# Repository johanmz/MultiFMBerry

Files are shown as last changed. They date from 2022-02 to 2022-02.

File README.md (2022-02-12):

FMBerry Logo
MultiFMBerry
=======
> Originally written by Tobias Mädel (t.maedel@alfeld.de, http://tbspace.de). Extended by Johan Muizelaar (https://github.com/johanmz) to control multiple transmitters.

> 

What is this? 
-------------
This is a fork of FMBerry from Tobias Mädel, a piece of software that allows you to transmit FM radio with your Raspberry Pi. The original software from Tobias allows you to control one transmitter, MultiFMBerry allows you to control multiple transmitters. The software is tested with 8 transmitters using a Raspberry Pi 3B but more should also be possible.

The goal was to create an alternative for analog cable FM after the switch-off, but even more just as a fun project.

How does it work? 
-------------
It uses Sony-Ericsson MMR-70 transmitters, which was originally intended for use with Sonys Walkman cellphones from early 2000s.
You can get these still for cheap from Ebay in 2022.

Why does it need additional IC's apart from the MRR70's?
-------------

Since all transmitters  use the same I²C address (0x66), one or more multiplexers (TCA9548A) are used to switch the transmitters before sending commands and RDS updates to the transmitters. Each TCA9548A has 8 I²C ports so it can handle 8 transmitters. One or more IO expanders (MCP23017) are used to read the RDS interrupt signals, this is the signal that the transmitter needs the next RDS block. Each MCP23017 can handle up to 16 transmitters. 

What do I need to build this? 
-------------
* MMR-70 transmitter, two or more. If you want to control only one transmitter, it makes more sense to use the software and hardware setup from Tobias since it doesn't need the additional IC's.
* Raspberry Pi (tested with 3B and 4B but see the limitations of the Pi4 in [AUDIO.md](audio/AUDIO.md) before you start!)
* TCA9548A, MCP23017 and AMS1117 breakout board(s) from AliExpress or Ebay
* Soldering equipment (soldering iron and some solder). Soldering skills.
* Thin wire to connect the transmitter boards to the TCA9548A and MCP23017 IC's, Dupont line cable (male to female) for the connection to the PI's GPIO connector.
* PCB prototype board (8 x 12 cm is fine, you can also mount the transmitters upright on the board) 
* USB sound card for each transmitter, the cheap "3D Sound" USB sound sticks from AliExpress work fine.
* One or more USB hubs if you have more than 4 transmitters. You need a hub with Multiple Transaction Translators (MTT). The BIG7 from UUgear and the Waveshare USB3.2 HAT (5 port) work fine and have the same form factor as the Pi as a bonus. See also [AUDIO.md](audio/AUDIO.md).

The hardware is explained here:
[HARDWARE.md](hardware/HARDWARE.md). This is my prototype with 8 MMR70 transmitters:

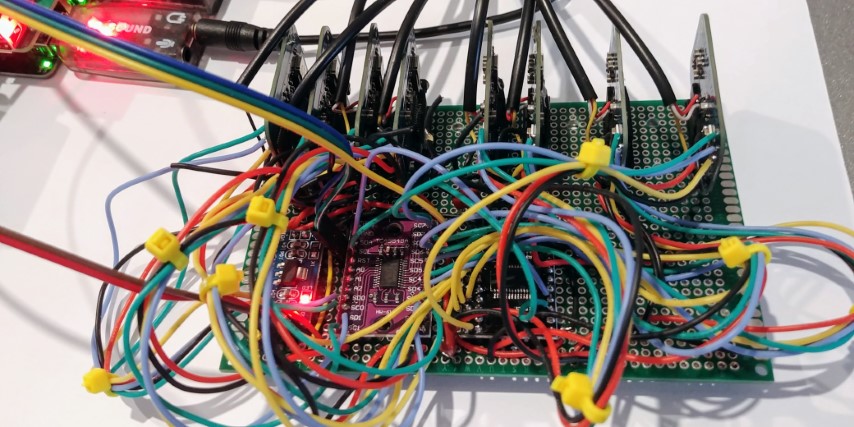
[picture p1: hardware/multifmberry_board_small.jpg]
MultiFMBerry board


How many transmitters and audio streams can one Pi control?
------------
It depends:

* The Raspberry Pi 4 has a limit of 4 USB sound cards due to limitations of the USB chipset. See [AUDIO.md](audio/AUDIO.md) for the issue and possible workarounds. On the Raspberry Pi 3B, you can use many more USB sound cards with a suitable USB hub, see next bullet.
* If you use a hub that does not support Multiple Transaction Translators (MTT), streaming to approx. more than 3 audio streams will result in severe distortion of the sound. See [AUDIO.md](audio/AUDIO.md). Use a hub with MTT.
* The Raspberry Pi OS Linux kernel has a limit of 8 sound cards. You can increase this limit by compiling your own kernel. See [AUDIO.md](audio/AUDIO.md)
* For RDS, the Pi (``fmberryd``) needs to send each 21,5ms data to each transmitter over the I²C bus. Not only the data needs to be sent but also the I²C commands to switch the multiplexer and read the IO expander. With many transmitters this will fully occupy the I²C bus, resulting in RDS display issues on the receiver. For more capacity, you can increase the speed of the I²C bus from 100Khz to 400Khz (see steps below) or disable RDS for some transmitters in the .conf file.
* Each audiostream uses about 5%-10% CPU. The Pi 3B has 4 cores which should be enough for many streams. FMBerry itself does not use much CPU either.
* The software itself has no practical limit for the number of transmitters. You need one TCA9548A per 8 transmitters and one MCP23017 per 16 transmitters. If you want to use more the 4 TCA9548A or MCP23017 IC's, increase the max in defs.h before compiling the software.

This software has been tested successfully with 8 transmitters on a Raspberry Pi 3B with 8 USB sound cards using a BIG7 UUgear USB hub, I plan to test with more transmitters. I've also done some limited but successful tests on a Pi 4B but switched to a Pi 3B when I found out about the USB sound card limit on the 4B.

Installation
-------------

### Step 1: Enabling I²C

Open raspi-blacklist.conf:

```
sudo nano /etc/modprobe.d/raspi-blacklist.conf
```

Comment out the Line "``blacklist i2c-bcm2708``" with a #.
Save with Ctrl+O and close nano with Ctrl+X

To make sure I²C Support is loaded at boottime open /etc/modules.

```
sudo nano /etc/modules
```

Add the following lines:

``i2c-dev``

Then again, Save with Ctrl+O and then close nano with Ctrl+X.

Please reboot your Raspberry after this step. 

### Step 2: Installing I²C tools and dependencies for the build

First update your local package repository with
```
sudo apt-get update
```

then install all needed software with the following command:
```
sudo apt-get install i2c-tools build-essential git libconfuse-dev
```

### Step 3: Speeding up the I²C bus

For RDS, every transmitter needs to receive data each 21,5ms over the I²C bus. Also, the I²C messages for the multiplexer and IO expander need to be send and received.  With more than 10 transmitters or so, the I²C bus speed should be increased to 400 KHz. 
```
sudo nano /boot/config.txt
```
Find the line ``dtparam=i2c`` and change it to ``dtparam=i2c_arm=on,i2c_arm_baudrate=400000``. Save and reboot.

### Step 4: Building the software
To build the software execute the following commands (in your homefolder):

```
git clone https://github.com/johanmz/MultiFMBerry.git
cd MultiFMBerry
make
```

Compiling the software will take a couple of seconds.

### Step 5: Specify your hardware in the config file
FMBerry needs to know about the MCP23017 IO expander, TCA9548A multiplexer, how many transmitters you have and to which TCA9548A and MCP23017 port each transmitter is connected. Specify this in the .conf file. 

In this file you can also specify the frequency, RDS information, etc for each transmitter.

If you want to modify the file after the make/compile, edit the fmberry.conf file in /etc.

### Step 6: Installing the software
FMBerry is essentially a daemon called fmberryd.
To install it into your system path type 
```
sudo make install
```

You can start it by typing 
```
sudo /etc/init.d/fmberry start
```

To control the daemon you have to use ctlfmberry.

It currently allows the following commands:
* ``ctlfmberry <tr> set freq 99000`` - Frequency in kHz (76000 - 108000)
* ``ctlfmberry <tr> poweron``
* ``ctlfmberry <tr> poweroff``
* ``ctlfmberry <tr> set rdsid DEADBEEF`` (8 chars! Longer strings will be truncated, shorter - padded with spaces)
* ``ctlfmberry <tr> set rdstext Mike Oldfield - Pictures in the Dark`` (max. 64 chars. Longer strings will be truncated)
* ``ctlfmberry <tr> set rdspi 0x7000`` - RDS PI between 0x0000 and 0xFFFF. Avoid locally used PI codes
* ``ctlfmberry <tr> set rdspty 10`` - RDS program type between 0 and 31
* ``ctlfmberry <tr> set txpwr 0`` - 0.5 mW Outputpower
* ``ctlfmberry <tr> set txpwr 1`` - 0.8 mW Outputpower
* ``ctlfmberry <tr> set txpwr 2`` - 1.0 mW Outputpower
* ``ctlfmberry <tr> set txpwr 3`` - 2.0 mW Outputpower (default)
* ``ctlfmberry <tr> stereo on`` - Enables stereo signal (default)
* ``ctlfmberry <tr> stereo off`` - Disables stereo signal
* ``ctlfmberry <tr> muteon`` - Mute audio (and 19KHz pilot signal and 38 KHz RDS sub-carrier)
* ``ctlfmberry <tr> muteoff`` - Unmute audio
* ``ctlfmberry <tr> gainlow`` - Audio gain -9dB
* ``ctlfmberry <tr> gainoff`` - Audio gain 0dB
* ``ctlfmberry <tr> set volume 0-6`` - Audio volume level 0 to 6, equal -9dB to +9db, 3dB step
* ``ctlfmberry <tr> status`` - Print current status
* ``ctlfmberry all stop`` - Stop FMBerry daemon
* ``ctlfmberry log`` - show logfile for FMBerry

``<tr>``: specify one or more transmitters or ``all`` for all transmitters.  Use names as specified in the fmberry.conf file, behind the 'transmitter' section header. 

Examples: 

``ctlfmberry 0,1 muteon`` 

``ctlfmberry 1 gainlow``

``ctlfmberry all muteoff``

Transmitter names are also shown in the status overview, run ``ctlfmberry all status``.
       
That's it! :)
### Step 7: Debugging
FMBerry writes debugging output to /var/log/syslog.

You can watch the information by running 
```
ctlfmberry log
```
It's essentially just a
 ```
 cat /var/log/syslog | grep fmberryd
 ```

It will tell you what's wrong. 

### Updating the software
Please check for new dependencies. You can safely just run the 
```
apt-get install
``` 
command again. It will only install new dependencies if necessary.

First stop the daemon by typing 
```
/etc/init.d/fmberry stop
``` 

Then run 
```
git pull
make
sudo make install
```

You can then start FMBerry again with 
```
/etc/init.d/fmberry start
```

## Notes
* WARNING! Tobias wrote that he is not a professional C programmer, neither am I. Please expect this software to have major security flaws. Please don't expose it's control port to the internet! I'm fairly certain that this software is vulnerable to buffer overflows. 
* If you are a C programmer, please help by securing this software and sending a pull request. 
* The Daemon itself is essentially a simple TCP server. It is listening to Port 42516. (set in fmberry.conf) You can control it by sending the exact same commands you would give to ctlfmberry.
* For information on How to control the Daemon have a look into ctlfmberry. It's a simple shell script.

## Common software problems

__The daemon does not show anything.__

That's normal. You have to use ./ctlfmberry to control the daemon.

__I can't seem to hear music.__

Turn up the volume/unmute your raspi with alsamixer.

__I am getting compile errors.__

Did you install all dependencies? (All lines with apt-get)

__Hardware issues__

See [HARDWARE.md](hardware/HARDWARE.md)

__Sound issues__

See [AUDIO.md](audio/AUDIO.md)

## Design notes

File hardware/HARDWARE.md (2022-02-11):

FMBerry - Hardware
=======

The following components are needed:
* one or more MMR70 transmitters
* one or more TCA9548A breakout boards. Each TCA9548A can handle up to 8 transmitters
* one ore more MCP23017 breakout boards. Each MCP23017 can handle up to 16 transmitters
* AMS1117 breakout board to convert the 5V of the Raspberry Pi to 3.3V. Each AMS1117 board should be able to handle up to 800mA. Each transmitter draws 27mA, the other IC's less.

Build your setup according to the schema below (click on it to enlarge). If you want to use less transmitters, simply omit them.

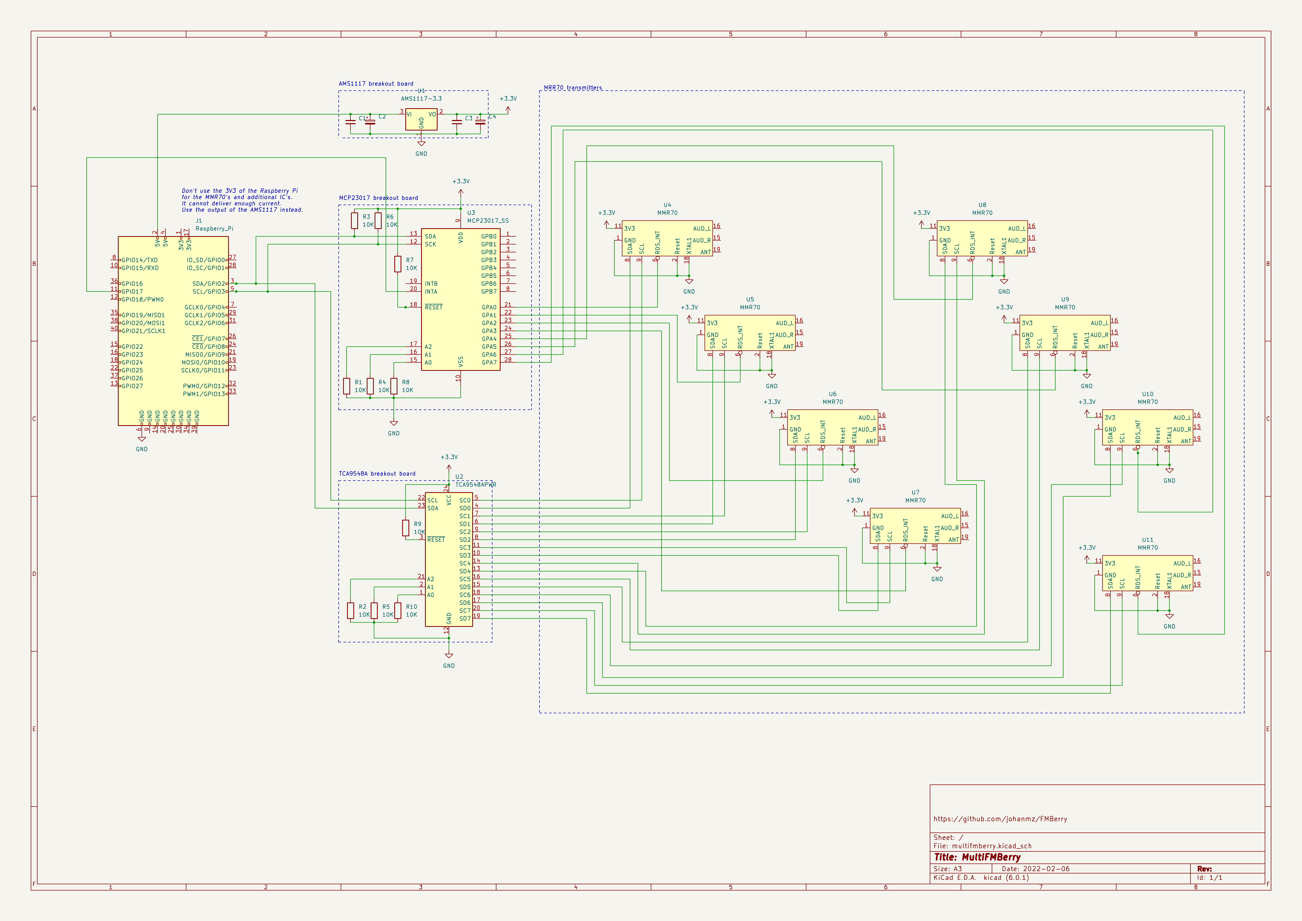
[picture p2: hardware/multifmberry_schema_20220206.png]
Schematic


Don't forget to disable the internal processor of the transmitter. This can be done easily by shorting on of it's crystal pins.
To do this connect TP18 to GND and TP2 to GND.
 
 Connect specific test points on the PCB of the MMR70 to the TCA9548A and MCP23017 IC's according to the schema. Also connect the 3.3V and GND.

Thanks to Oliver J. (skriptkiddy) for the schematics and the photo with all named test points.
Thanks to Andrey Chilikin for the excellent photo with all test points labeled.

[Schematic of the MMR-70](http://www.mikrocontroller.net/attachment/140251/MMR70.pdf)

Test points

Test points

Raspberry Pi pins

External antenna, a wire (300/(frequency in MHz) * 25) cm long, can be connected to TP19 or to TP20 - the only test point on back side of MMR-70

Connect a sound cable with 3,5" jack to the audio input test points:

* Audio GND -- TP1
* Audio R   -- TP15
* Audio L   -- TP16

And plug it into a USB sound card.

Checking the transmitters
------------
The TCA9548A uses I²C port 0x70, the MCP23017 I²C port 0x20. Check with ``i2cdetect -y 1`` if your Raspberry Pi can see them.

```
pi@multifmberry:~ $ i2cdetect -y 1
     0  1  2  3  4  5  6  7  8  9  a  b  c  d  e  f
00:                         -- -- -- -- -- -- -- --
10: -- -- -- -- -- -- -- -- -- -- -- -- -- -- -- --
20: 20 -- -- -- -- -- -- -- -- -- -- -- -- -- -- --
30: -- -- -- -- -- -- -- -- -- -- -- -- -- -- -- --
40: -- -- -- -- -- -- -- -- -- -- -- -- -- -- -- --
50: -- -- -- -- -- -- -- -- -- -- -- -- -- -- -- --
60: -- -- -- -- -- -- -- -- -- -- -- -- -- -- -- --
70: 70 -- -- -- -- -- -- --
```
Switch the TCA9548A to transmitter 1 and check again. Now you should see also the MMR70 on I²C port 0x66:
```
pi@multifmberry:~ $ i2cset -y 1 0x70 1
pi@multifmberry:~ $ i2cdetect -y 1
     0  1  2  3  4  5  6  7  8  9  a  b  c  d  e  f
00:                         -- -- -- -- -- -- -- --
10: -- -- -- -- -- -- -- -- -- -- -- -- -- -- -- --
20: 20 -- -- -- -- -- -- -- -- -- -- -- -- -- -- --
30: -- -- -- -- -- -- -- -- -- -- -- -- -- -- -- --
40: -- -- -- -- -- -- -- -- -- -- -- -- -- -- -- --
50: -- -- -- -- -- -- -- -- -- -- -- -- -- -- -- --
60: -- -- -- -- -- -- 66 -- -- -- -- -- -- -- -- --
70: 70 -- -- -- -- -- -- --
```
This way you can check all transmitters. Note that you have to send the bit corresponding to the port, so ``i2cset -y 1 0x70 2`` for transmitter 2, ``i2cset -y 1 0x70 4`` for transmitter 3, ``i2cset -y 1 0x70 8`` for transmitter 4, etc.

## Setup fmberry.conf

The software needs to know about your hardware setup. Modify fmberry.conf according to your needs. The sample config file matches the 8 transmitter setup of the schematic above. For less than 8 transmitters, simpy delete the corresponding transmitter sections from the fmberry.conf file.

The config file can be found (after the make install) in /etc/fmberry.conf

That's it! 

## Common hardware problems

__Transmitters cannot be heard__

Check if /etc/fmberry.conf file is setup correctly. Check the IO expander section and in the Transmitter section the IO expander reference and the multiplexer port and addresses.

Check the hardware.

See ``Checking the transmitters`` section above.

Check the log file with ``ctlfmberry log`` for errors.

__The power supply of the raspberry pi shorts out/there are no lights anymore__

There is a short circuit. Probably caused by a wiring fault

__Transmitters work but no RDS__

Make sure the connections between the transmitter and the MCP23017 are setup correct. Also make sure the MCP23017 is connected to the Raspberry Pi according to the schema.

Check the IO expander section in /etc/fmberry.conf and check if the IO Expander port setting in the Transmitter sections match the correct IO expander section and port.

RDS disabled in the fmberry.conf file (this can be set for each transmitter).

Make sure that your radio is close enough to the transmitter or connect an antenna wire to test point 19 of the transmitters. Also, the PI and additional IC's can generate so much RF that the reception is affected.

__RDS incorrect, letters missing__

Make sure that your radio is close enough to the transmitter or connect an antenna wire to test point 19 of the transmitters. Also, the PI and additional IC's can generate so much RF that the reception is affected.

If you have a large number of transmitters (more than 10-15 or so), the I²C bus might be fully occupied. Increase the I²C rate from 100Khz to 400Khz, see [README.md](../README.md).

__The transmission dies after a couple of minutes__

You didn't disable the internal processor of the MMR70(s). Do this by connecting TP18 to GND.

## I want to connect more than 8 transmitters

__NOTE: I haven't tested this yet, it might or might not work__

The software is capable of handling more than 8 transmitters. 

__Additional hardware__
You'll need an additional TCA9548A if you want to connect more than 8 transmitters. The MCP23017 can handle 16 transmitters but for practical reasons you might also want to use a second MCP23017.
Each MCP23017 needs to be connected to a unique suitable GPIO pin on the Raspberry Pi. 

Give the additional TCA9548A and MCP23017 unique I²C addresses by connecting one or more A0/A1/A2 address selector lines to 3V3. 

Connect the SDA and SCL lines of the additional TCA9548A and MCP23017 with the Raspberry Pi (in parallel with the existing connections).

Be careful that you don't exceed the max current of the AMS1117, use additional AMS1117 breakout boards if you exceed the max current. Don't take risks, there are reports that some AMS1117 IC's from dubious chipmakers have no overcurrent protection and output 5V when overloaded.

__Update fmberry.conf__

Make sure that you add an IO Expander section with the corresponding unique I²C address in the fmberry.conf file for each additional MCP23017

Add transmitter sections, give each transmitter section a unique name. Don't forget to use the correct TCA9548A address and port in the transmitter sections and refer to the new IO expander section of the additional MCP23017.

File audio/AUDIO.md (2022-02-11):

MultiFMBerry - Audio
=======

## USB sound cards

If you want to stream audio from your Pi to the transmitters you need USB sound cards. Cheap ones are fine, as long as they are supported by the Pi. I've used very cheap "3D Sound" USB sound cards from AliExpress (reporting themselves as Generalplus or C-Media chipset)

__Limitations of Raspberry Pi 4B__

Unfortunately the Raspberry Pi 4B can only handle 4 sound cards due to limitations of the USB chipset (and according to some reports sometimes even less, depending on the sound card used). Using a hub connected to one of the normal USB ports does not solve the problem since the limitation is in the USB chipset of the Pi 4B.
See https://forums.raspberrypi.com/viewtopic.php?t=263124 and https://github.com/raspberrypi/linux/issues/3962

As a workaround, it should be possible to connect a USB-C hub to the USB-C power connector of the Pi 4B, using the OTG functionality. The Pi then either has to be powered to the USB-C hub (Power Delivery) or through the 5V GPIO pins. I haven't tried this myself. See https://github.com/raspberrypi/linux/issues/3962#issuecomment-733653714

The Raspberry Pi 3B does not have this problem, the hardware supports much more USB sound cards.

__8 sound cards limit of the Raspberry Pi OS Linux kernel__

Raspberry Pi OS has by default a limitation of 8 sound cards. Fortunately it's easy to increase this by changing the kernel configurations and building the kernel yourself.  

Instructions: https://www.raspberrypi.com/documentation/computers/linux_kernel.html

Change the following parameters: ``CONFIG_SND_DYNAMIC_MINORS=Y`` and ``CONFIG_MAX_CARDS=32`` (or set it to any value you need).
You can use ``menuconfig`` to do this, the settings can be found here: ``Device Drivers/Sound card support/Advanced Linux Sound Architecture/Dynamic device file minor numbers`` and ``Max number of sound cards``.

NB: Ubuntu 64 bit for Raspberry Pi already has a 32 sound card limit by default. 

## USB Hub

The Raspberry Pi has 4 USB ports, so if you want to stream and have more than 4 transmitters you need one or more USB hubs. 

Since most if not all USB Sound cards are operating at no more than Full Speed, you need a hub that support Multiple Transaction Translators (MTT). If your hub only has a Single Transaction Translator (STT), sound will be distorted when using approx 3,4 USB sound cards or more. Therefore you need a MTT hub.

You can check if your hub has MTT or STT with ``lsusb -v``. Warning: the build-in hub of the Pi will also be displayed, don't mix them up. Run the command first without the external USB hub and writing down the Bus and Device numbers of the internal hub. 
Look for ``bDeviceProtocol``, value 2 is MTT (good). Example from the BIG7 from UUgear:
```
lsusb -v

...

Bus 001 Device 004: ID 1a40:0201 Terminus Technology Inc. FE 2.1 7-port Hub
Couldn't open device, some information will be missing
Device Descriptor:
  bLength                18
  bDescriptorType         1
  bcdUSB               2.00
  bDeviceClass            9 Hub
  bDeviceSubClass         0
  bDeviceProtocol         2 TT per port
  bMaxPacketSize0        64
  idVendor           0x1a40 Terminus Technology Inc.
  idProduct          0x0201 FE 2.1 7-port Hub
  bcdDevice            1.00
  iManufacturer           0
  iProduct                1 USB 2.0 Hub [MTT]
  iSerial                 0
  bNumConfigurations      1
  Configuration Descriptor:

  ...
```

Unfortunately many vendors don't specify whether the hub is STT or MTT or the name of the chipset used so that you can look it up yourself in the datasheet. USB3 is also no guarantee for MTT capabilities. USB Hubs that do work, so with MTT, and also fit nicely on a Raspberry Pi (optional, but nice bonus) are the Waveshare USB 3.2 HUB HAT (5 ports) and UUgear BIG7 (7 ports). 

## Map ALSA card names to USB ports

With the help of UDEV rules, fixed ALSA card names can be assigned to USB ports. This prevents mingling your audio streams after reboots or plugging in/out USB sound cards.

### Step 1
First, check the device path (DEVPATH) for each of your USB sound cards by running the command below and then plugging in your USB devices one by one. Copy the value of each device path to a text editor, you'll need that in the next step.

```
pi@multifmberry:~ $ udevadm monitor --kernel --property --subsystem-match=sound
monitor will print the received events for:
KERNEL - the kernel uevent

KERNEL[646.140751] add      /devices/platform/soc/3f980000.usb/usb1/1-1/1-1.1/1-1.1.3/1-1.1.3.1/1-1.1.3.1:1.0/sound/card1 (sound)
ACTION=add
DEVPATH=/devices/platform/soc/3f980000.usb/usb1/1-1/1-1.1/1-1.1.3/1-1.1.3.1/1-1.1.3.1:1.0/sound/card1
SUBSYSTEM=sound
SEQNUM=1678

...
````
### Step 2

Use the DEVPATH found in the previous step to create a file ``/etc/udev/rules.d/85-my-usb-audio.rules`` similar to the one below. Use your favorite text editor, for example ``sudo nano /etc/udev/rules.d/85-my-usb-audio.rules``

```
SUBSYSTEM!="sound", GOTO="my_usb_audio_end"
ACTION!="add", GOTO="my_usb_audio_end"

DEVPATH=="/devices/platform/soc/3f980000.usb/usb1/1-1/1-1.1/1-1.1.3/1-1.1.3.1/1-1.1.3.1:1.0/sound/card?", ATTR{id}="FMBERRY_0"
DEVPATH=="/devices/platform/soc/3f980000.usb/usb1/1-1/1-1.1/1-1.1.3/1-1.1.3.2/1-1.1.3.2:1.0/sound/card?", ATTR{id}="FMBERRY_1"
DEVPATH=="/devices/platform/soc/3f980000.usb/usb1/1-1/1-1.1/1-1.1.3/1-1.1.3.3/1-1.1.3.3:1.0/sound/card?", ATTR{id}="FMBERRY_2"
DEVPATH=="/devices/platform/soc/3f980000.usb/usb1/1-1/1-1.1/1-1.1.3/1-1.1.3.4/1-1.1.3.4:1.0/sound/card?", ATTR{id}="FMBERRY_3"
DEVPATH=="/devices/platform/soc/3f980000.usb/usb1/1-1/1-1.1/1-1.1.3/1-1.1.3.7/1-1.1.3.7:1.0/sound/card?", ATTR{id}="FMBERRY_4"
DEVPATH=="/devices/platform/soc/3f980000.usb/usb1/1-1/1-1.1/1-1.1.3/1-1.1.3.6/1-1.1.3.6:1.0/sound/card?", ATTR{id}="FMBERRY_5"
DEVPATH=="/devices/platform/soc/3f980000.usb/usb1/1-1/1-1.1/1-1.1.3/1-1.1.3.5/1-1.1.3.5:1.0/sound/card?", ATTR{id}="FMBERRY_6"
DEVPATH=="/devices/platform/soc/3f980000.usb/usb1/1-1/1-1.1/1-1.1.2/1-1.1.2:1.0/sound/card?", ATTR{id}="FMBERRY_7"

LABEL="my_usb_audio_end"
```

Note that the last character, the card number, in the DEVPATH found with udevadm is replaced with a ``?``. 

### Step 3

Check the results:
```
pi@multifmberry:~ $ cat /proc/asound/cards
 0 [FMBERRY_1      ]: USB-Audio - USB Audio Device
                      GeneralPlus USB Audio Device at usb-3f980000.usb-1.1.3.2, full speed
 1 [FMBERRY_0      ]: USB-Audio - USB Audio Device
                      GeneralPlus USB Audio Device at usb-3f980000.usb-1.1.3.1, full speed
 2 [FMBERRY_7      ]: USB-Audio - USB Audio Device
                      GeneralPlus USB Audio Device at usb-3f980000.usb-1.1.2, full speed
 3 [FMBERRY_2      ]: USB-Audio - USB Audio Device
                      GeneralPlus USB Audio Device at usb-3f980000.usb-1.1.3.3, full speed
 4 [FMBERRY_3      ]: USB-Audio - USB Audio Device
                      GeneralPlus USB Audio Device at usb-3f980000.usb-1.1.3.4, full speed
 5 [FMBERRY_6      ]: USB-Audio - USB PnP Sound Device
                      C-Media Electronics Inc. USB PnP Sound Device at usb-3f980000.usb-1.1.3.5, full
 6 [FMBERRY_5      ]: USB-Audio - USB Audio Device
                      GeneralPlus USB Audio Device at usb-3f980000.usb-1.1.3.6, full speed
 7 [FMBERRY_4      ]: USB-Audio - USB Audio Device
                      GeneralPlus USB Audio Device at usb-3f980000.usb-1.1.3.7, full speed
 8 [vc4hdmi        ]: vc4-hdmi - vc4-hdmi
                      vc4-hdmi
```
 See also https://alsa.opensrc.org/Udev.

## Streaming audio

VLC example (install with ``sudo apt install vlc``) : 
```
#When UDEV rules have been setup as described above
cvlc --http-reconnect --aout=alsa --alsa-audio-device=hw:FMBERRY_2,0 $URL
cvlc --http-reconnect --aout=alsa --alsa-audio-device=hw:FMBERRY_3,0 $OTHERURL

#Send vlc to the background
cvlc --http-reconnect --aout=alsa --alsa-audio-device=hw:FMBERRY_2,0 $URL &
cvlc --http-reconnect --aout=alsa --alsa-audio-device=hw:FMBERRY_3,0 $OTHERURL &

#When you haven't setup UDEV rules as described above
cvlc --http-reconnect --aout=alsa --alsa-audio-device=hw:2,0 $URL
cvlc --http-reconnect --aout=alsa --alsa-audio-device=hw:3,0 $OTHERURL

#this uses much more CPU so better not do this
cvlc --http-reconnect --aout=alsa --alsa-audio-device=default:CARD=Device_2 $OTHERURL
```
Where $URL and $OTHERURL are the streams of your favorite radio stations

Mplayer example:
```
#When UDEV rules have been setup as described above 
mplayer -vo null -ao alsa:device=hw=FMBERRY_2.0 $URL 

#When you haven't setup UDEV rules as described above
mplayer -vo null -ao alsa:device=hw=2.0 $URL
```

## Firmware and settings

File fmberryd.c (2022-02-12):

/*
	FMBerry - an cheap and easy way of transmitting music with your Pi.
    Copyright (C) 2011-2013 by Tobias Mädel (t.maedel@alfeld.de)
	Copyright (C) 2013      by Andrey Chilikin (https://github.com/achilikin)
	Copyright (C) 2021      by Johan Muizelaar - modifications for multiple fm transmitters - (https://github.com/johanmz)

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
    You should have received a copy of the GNU General Public License
    along with this program.  If not, see <http://www.gnu.org/licenses/>.
*/
#include "fmberryd.h"
#include "rpi_pin.h"
#include "ns741.h"
#include "tca9548a.h"
#include "mcp23017.h"

#include <poll.h>
#include <stdlib.h>
#include <syslog.h>
#include <string.h>
#include <unistd.h>
#include <confuse.h>
#include <sys/stat.h>
#include <netinet/in.h>
#include "defs.h"

#define RPI_REVISION RPI_REV2

mmr70_data_t mmr70[MAXTRANSMITTERS];
IOexpander_data_t IOexpander[MAXIOEXPANDERS];
multiplexer_data_t multiplexer[MAXMULTIPLEXERS];

static cfg_t *cfg, *cfg_transmitter, *cfg_IOexpander;
static volatile int run = 1;
static int start_daemon = 1;

static int IOexpander_to_mmr70[MAXIOEXPANDERS][16]; // lookup which transmitter belongs to which mcp23017 por, in handling rds interupts
static int nr_transmitters =0; 

int main(int argc, char **argv)
{
	//Check if user == root
	// if(geteuid() != 0)
	// {
	//   puts("Please run this software as root!");
	//   exit(EXIT_FAILURE);
	// }

	// check for non-daemon mode for debugging
	for(int i = 1; i < argc; i++) {
		if (str_is(argv[i], "nodaemon")) {
			start_daemon = 0;
			break;
		}
	}

	if (start_daemon) {
		//Init daemon, can be replaced with daemon() call
		pid_t pid;

		pid = fork();
		if (pid < 0) {
			exit(EXIT_FAILURE);
		}
		if (pid > 0) {
			exit(EXIT_SUCCESS);
		}

		umask(0);

		//We are now running as the forked child process.
		openlog(argv[0],LOG_NOWAIT|LOG_PID,LOG_USER);

		pid_t sid;
		sid = setsid();
		if (sid < 0) {
			syslog(LOG_ERR, "Could not create process group\n");
			exit(EXIT_FAILURE);
		}

		if ((chdir("/")) < 0) {
			syslog(LOG_ERR, "Could not change working directory to /\n");
			exit(EXIT_FAILURE);
		}
	}
	else {
		// open syslog for non-daemon mode
		openlog(argv[0],LOG_NOWAIT|LOG_PID,LOG_USER);
	}

	//Read configuration file
	cfg_opt_t transmitter_opts[] = {
			CFG_STR_LIST("transmitter", "{1}", CFGF_NONE),
			CFG_INT("frequency", 99800, CFGF_NONE),
			CFG_BOOL("stereo", 1, CFGF_NONE),
			CFG_BOOL("rdsenable", 1, CFGF_NONE),
			CFG_BOOL("poweron", 1, CFGF_NONE),
			CFG_INT("txpower", 3, CFGF_NONE),
			CFG_BOOL("gain", 0, CFGF_NONE),
			CFG_INT("volume", 3, CFGF_NONE),
			CFG_STR("rdsid", "", CFGF_NONE),
			CFG_STR("rdstext", "", CFGF_NONE),
			CFG_INT("rdspi", 0x8000, CFGF_NONE),
			CFG_INT("rdspty", 10, CFGF_NONE),
			CFG_INT("i2cmultiplexeraddress", 0x70, CFGF_NONE),
			CFG_INT("i2cmultiplexerport", 0, CFGF_NONE),
			CFG_STR("IOexpanderconfig", "1_Aports", CFGF_NONE),
			CFG_INT("IOexpanderport",0, CFGF_NONE),
			CFG_END()
		};

	cfg_opt_t IOexpander_opts[]= {	CFG_STR_LIST("IOexpander", "{1_Aports}", CFGF_NONE),
			CFG_INT("IOexpanderaddress", 0x20, CFGF_NONE),
			CFG_INT("IOinterruptpin", 17, CFGF_NONE),
			CFG_END()}
		;

	cfg_opt_t opts[] = {
			CFG_INT("i2cbus", 1, CFGF_NONE),
			CFG_BOOL("tcpbindlocal", 1, CFGF_NONE),
			CFG_INT("tcpport", 42516, CFGF_NONE),
			CFG_INT("rdspin", 17, CFGF_NONE),
			CFG_INT("ledpin", 27, CFGF_NONE),
			CFG_SEC("transmitter", transmitter_opts, CFGF_TITLE | CFGF_MULTI),
			CFG_SEC("IOexpander", IOexpander_opts, CFGF_TITLE | CFGF_MULTI),
			CFG_END()
		};

	cfg = cfg_init(opts, CFGF_NONE);
	if (start_daemon) {
		if (cfg_parse(cfg, "/etc/fmberry.conf") == CFG_PARSE_ERROR)
			return 1;
	}
	else {
	if (cfg_parse(cfg, "/home/pi/git/FMBerry/fmberry.conf") == CFG_PARSE_ERROR)
		return 1;
	}	
	//rdsint = cfg_getint(cfg, "rdspin");

	int nfds;
	struct pollfd  polls[MAXIOEXPANDERS+1]; //+1 for the tcp polling

	//open TCP listener socket, will exit() in case of error
	int tcpport = cfg_getint(cfg, "tcpport");
	int lst = ListenTCP(cfg_getint(cfg, "tcpport"));
	polls[0].fd = lst;
	polls[0].events = POLLIN;
	polls[0].revents=0;
	nfds = 1;


	// read IOexpander data from config
	int nr_IOexpanders =  cfg_size(cfg, "IOexpander");
	bzero(&IOexpander, sizeof(IOexpander));
	for (int k=0; k < nr_IOexpanders; k++) {
		cfg_IOexpander 				= cfg_getnsec(cfg, "IOexpander", k);
		strncpy(IOexpander[k].id, cfg_title(cfg_IOexpander), 12);
		IOexpander[k].address 		= cfg_getint (cfg_IOexpander, "IOexpanderaddress");
		IOexpander[k].interruptpin 	= cfg_getint (cfg_IOexpander, "IOinterruptpin");
	}

	// initialize data structure for 'status' command
	nr_transmitters = cfg_size(cfg, "transmitter");
	bzero(&mmr70, sizeof(mmr70));
	for (int j = 0; j < nr_transmitters; j++) {	
		cfg_transmitter 			= cfg_getnsec(cfg, "transmitter", j);
		strncpy(mmr70[j].name, cfg_title(cfg_transmitter), 32);
		mmr70[j].frequency 			= cfg_getint(cfg_transmitter, "frequency");
		mmr70[j].power 				= cfg_getbool(cfg_transmitter, "poweron");
		mmr70[j].txpower 			= cfg_getint(cfg_transmitter, "txpower");
		mmr70[j].mute 				= 0;
		mmr70[j].gain 				= cfg_getbool(cfg_transmitter, "gain");
		mmr70[j].volume 			= cfg_getint(cfg_transmitter, "volume");
		mmr70[j].stereo 			= cfg_getbool(cfg_transmitter, "stereo");
		mmr70[j].rds 				= cfg_getbool(cfg_transmitter, "rdsenable");
		strncpy(mmr70[j].rdsid, cfg_getstr(cfg_transmitter, "rdsid"), 8);
		strncpy(mmr70[j].rdstext, cfg_getstr(cfg_transmitter, "rdstext"), 64);
		mmr70[j].rdspi 				= cfg_getint(cfg_transmitter, "rdspi");
		mmr70[j].rdspty 			= cfg_getint(cfg_transmitter, "rdspty");
		mmr70[j].i2c_mplexaddress 	= cfg_getint(cfg_transmitter, "i2cmultiplexeraddress");
		mmr70[j].i2c_mplexport	 	= cfg_getint(cfg_transmitter, "i2cmultiplexerport");
		strncpy(mmr70[j].IOexpanderconfig, cfg_getstr(cfg_transmitter, "IOexpanderconfig"), 12);
		mmr70[j].IOexpanderindex = -1;
		for (int k =0; k<nr_IOexpanders;k++)
			if (!strcmp(IOexpander[k].id, mmr70[j].IOexpanderconfig)) {
				mmr70[j].IOexpanderindex = k;
				break;
			}
		if (mmr70[j].IOexpanderindex == -1) {
			syslog(LOG_ERR, "Error with matching IOExpander config for transmitter with IOexpander config section. Correct .conf file. \n");
			exit(EXIT_FAILURE);
		}
		mmr70[j].IOexpanderport 	= cfg_getint(cfg_transmitter, "IOexpanderport");
	}
	
	//build up table so that we quickly can lookup which transmitter belongs to which mcp23017 port while handling rds interupts 
	for (int j=0; j<nr_IOexpanders;j++)
		for (int k=0;k<16;k++)
			IOexpander_to_mmr70[j][k] = -1;
	for (int l=0;l<nr_transmitters;l++)
		IOexpander_to_mmr70[mmr70[l].IOexpanderindex][mmr70[l].IOexpanderport]=l;
	
	// build up index for the multiplexers for initialisation of the i2cbus
	// use the index number for each multiplexer also for 
	int mplex_found;
	int mplexindex=-1;
	bzero(&multiplexer, sizeof(multiplexer));
	for (int j = 0; j < nr_transmitters; j++)
	{
		mplex_found = -1;
		for (int k=0; k < MAXMULTIPLEXERS; k++) {
			if (multiplexer[k].address == mmr70[j].i2c_mplexaddress) {	
				mplex_found = k;
				break;
			}
		}
		if (mplex_found != -1)
			mmr70[j].i2c_mplexindex = mplex_found;
		else {
			mplexindex++;
			multiplexer[mplexindex].address=mmr70[j].i2c_mplexaddress;
			mmr70[j].i2c_mplexindex = mplexindex;
		}
	}



	// initialize the ns741 register map for all transmitters and initialise rds_ps & rds_text registers
	ns741_init_registers(nr_transmitters);

	// initialize all tca9548a multiplexer i2c busses
	if (tca9548a_init_i2c(cfg_getint(cfg, "i2cbus"))==-1) {
		syslog(LOG_ERR, "Init of TCA9548A multiplexer(s) failed! Double-check hardware and .conf and try again!\n");
		syslog(LOG_ERR, "And check if user is either root or has i2c read/write rights, verify with i2cdetect -y 1\n");
		exit(EXIT_FAILURE);
	}
	syslog(LOG_NOTICE, "Successfully initialized i2c bus for TCA9548A multiplexer(s).\n");

	// init I2C bus for the mcp23017 IC expander(s)
	if (mcp23017_init_i2c(cfg_getint(cfg, "i2cbus")) == -1 || mcp23017_init_INT(nr_transmitters)==-1) {
		syslog(LOG_ERR, "Init of mcp23017 IO expander(s) failed! Double-check hardware and .conf and try again!\n");
		exit(EXIT_FAILURE);
	}
	syslog(LOG_NOTICE, "Successfully initialized i2c bus for mcp23017 IO expander(s)\n");

	// init I2C bus and transmitters with initial frequency and state
	if (ns741_init_i2c(cfg_getint(cfg, "i2cbus"), nr_transmitters) == -1) {
		syslog(LOG_ERR, "Init of transmitters failed! Double-check hardware and .conf and try again!\n");
		exit(EXIT_FAILURE);
	}
	syslog(LOG_NOTICE, "Successfully initialized ns741 transmitters.\n");


	// apply configuration parameters
	for (int j = 0; j< nr_transmitters; j++) {
		// enable the transmitter i2c port on the tca9548a 
		tca9548a_select_port(mmr70[j].i2c_mplexindex, mmr70[j].i2c_mplexport);
		// and set the parameters on the transmitter
		ns741_set_frequency (j, mmr70[j].frequency);
		ns741_txpwr(j, mmr70[j].txpower);
		ns741_mute(j, mmr70[j].mute);
		ns741_stereo(j, mmr70[j].stereo);
		ns741_init_rds_registers(j);
		ns741_rds_set_progname(j, mmr70[j].rdsid);
		ns741_rds_set_radiotext(j, mmr70[j].rdstext);
		ns741_rds_set_rds_pi(j, mmr70[j].rdspi);
		ns741_rds_set_rds_pty(j, mmr70[j].rdspty);
		ns741_power(j, mmr70[j].power);
		ns741_input_gain(j, mmr70[j].gain);
		ns741_volume(j, mmr70[j].volume);
	}

	// ns741_rds_debug(1);
	// Use RPI_REV1 for earlier versions of Raspberry Pi
	rpi_pin_init(RPI_REVISION);

	int rds;
	int rdsint;
	for (int j=0;j < nr_IOexpanders;j++) {
		// Get file descriptor for RDS handler
		polls[j+1].revents = 0;
		rdsint=IOexpander[j].interruptpin;
		rds = rpi_pin_poll_enable(rdsint, EDGE_FALLING);
	    if (rds < 0) {
	        printf("Couldn't enable RDS support\n");
			syslog(LOG_ERR, "Could not enable RDS support\n");
	        run = 0;
			break;
	    }
		polls[j+1].fd = rds;
		polls[j+1].events = POLLPRI;
		nfds = 1+nr_IOexpanders;
	}

	// send first two bytes for each transmitter	
	for (int k=0;k<nr_transmitters;k++) {
		if (tca9548a_select_port(mmr70[k].i2c_mplexindex,mmr70[k].i2c_mplexport) == -1) {
			syslog(LOG_ERR, "Could not switch tca9548a\n");
			exit(EXIT_FAILURE);
		}
		ns741_rds(k, mmr70[k].rds);
		ns741_rds_isr(k); 
	}
	

	// main polling loop
	uint16_t trs_rdsstatus;
	uint8_t transmitter;
	int ledcounter = 0;
	int intr_notfinished=99;
	while(run) {
		
		// alternative loop to run without interrupts, however this fully saturates the i2c bus
		// for (int j = 0; j<nr_IOexpanders;j++)
		// {
		// 	trs_rdsstatus = ~mcp23017_read_trs_rdsstatus(j); 
		// 	trs_rdsstatus &= IOexpander[j].GPINTEN;
		// 	for (int k=0;k<16;k++)
		// 	{
		// 		if (trs_rdsstatus & 0x0001)
		// 		{
		// 			transmitter = IOexpander_to_mmr70[j][k];
		// 			if (tca9548a_select_port (mmr70[transmitter].i2c_mplexindex, mmr70[transmitter].i2c_mplexport) == -1)
		// 			{
		// 				syslog(LOG_ERR, "Port switch tca9548a failed during RDS update\n");
		// 				exit(EXIT_FAILURE);	
		// 			}
		// 			else
		// 			{
		// 				ns741_rds_isr(transmitter);
		// 			}
		// 		}
		// 		trs_rdsstatus >>= 1;
		// 	}
		// }
			
		// if new interrupts from transmitter came during the previous processing, first handle these
		// if all done then wait for the next interrupt
		// note that the interruptpin of the mcp20317 will only return to high if there are no more MRR70's with the interrupt low AND the GPIO register of the MCP23017 is read
		for (int j = 0; j<nr_IOexpanders;j++)
			if (IOexpander[j].intr_notfinished) {
				intr_notfinished = 1;
				break;
			}
		if (!intr_notfinished) 
			if (poll(polls, nfds, 25) < 0)
				break;

		for (int j=0;j<nr_IOexpanders;j++)
		{
			if (polls[j+1].revents || IOexpander[j].intr_notfinished || intr_notfinished == 99) {
				trs_rdsstatus = ~mcp23017_read_trs_rdsstatus(j); 
				trs_rdsstatus &= IOexpander[j].GPINTEN;
				for (int k=0;k<16;k++) {
					if (trs_rdsstatus & 0x0001) {
						transmitter = IOexpander_to_mmr70[j][k];
						tca9548a_select_port (mmr70[transmitter].i2c_mplexindex, mmr70[transmitter].i2c_mplexport);
						ns741_rds_isr(transmitter);
					}
					trs_rdsstatus >>= 1;
				}
				//while processing this interrupt, new transmitters might have send an interrupt, remember this for the next run. This also clears the intrrupt pin
				intr_notfinished = 0;
				IOexpander[j].intr_notfinished = (rpi_pin_get(IOexpander[j].interruptpin) == 0) ? 1 : 0;
			}
		}
		if (polls[0].revents)
			 ProcessTCP(lst);
	}

	//clean up at exit
	for (int j=0;j<nr_transmitters;j++)
		ns741_power(transmitter, 0);
	
	for (int j=0;j<MAXIOEXPANDERS;j++)
		if (IOexpander[j].interruptpin) {
			rpi_pin_unexport(IOexpander[j].interruptpin);
			break;
		}

	close(lst);
	closelog();

	return 0;
}


int ListenTCP(uint16_t port)
{
	// Socket erstellen - TCP, IPv4, keine Optionen 
	int lsd = socket(AF_INET, SOCK_STREAM, 0);

	// IPv4, Port: 1111, jede IP-Adresse akzeptieren 
	struct sockaddr_in saddr;
	saddr.sin_family = AF_INET;
	saddr.sin_port = htons(port);
	if (cfg_getbool(cfg, "tcpbindlocal"))
	{
		syslog(LOG_NOTICE, "Binding to localhost.\n");
    	saddr.sin_addr.s_addr = htonl(INADDR_LOOPBACK);
    }
	else
	{
		syslog(LOG_NOTICE, "Binding to any interface.\n");
    	saddr.sin_addr.s_addr = htonl(INADDR_ANY);
    }

	//Important! Makes sure you can restart the daemon without any problems!
	const int       optVal = 1;
	const socklen_t optLen = sizeof(optVal);

	int rtn = setsockopt(lsd, SOL_SOCKET, SO_REUSEADDR, (void*) &optVal, optLen);

	//assert(rtn == 0);   // this is optional 

	// Socket an Port binden 
	if (bind(lsd, (struct sockaddr*) &saddr, sizeof(saddr)) < 0) {
  		//whoops. Could not listen
  		syslog(LOG_ERR, "Could not bind to TCP port! Terminated.\n");
  		exit(EXIT_FAILURE);
	 }

  	syslog(LOG_NOTICE, "Successfully started daemon\n");
	// Auf Socket horchen (Listen) 
	listen(lsd, 10);

	return lsd;
}

// for 'status' command
static float txpower[4] = { 0.5, 0.8, 1.0, 2.0 };

// int ProcessTCP(int sock, mmr70_data_t *pdata)
int ProcessTCP(int sock)
{
	// Puffer und Strukturen anlegen
	struct sockaddr_in clientaddr;
	socklen_t clen = sizeof(clientaddr);
	char arg_buffer[512];
	bzero(arg_buffer, sizeof(arg_buffer));
	char full_buffer[512];
	bzero(full_buffer, sizeof(full_buffer));

	// Auf Verbindung warten, bei Verbindung Connected-Socket erstellen 
	int csd = accept(sock, (struct sockaddr *)&clientaddr, &clen);

	struct pollfd  pol;
	pol.fd = csd;
	pol.events = POLLRDNORM;

	// just to be on a safe side check if data is available
	if (poll(&pol, 1, 1000) <= 0) {
		close(csd);
		return -1;
	}

	int len  = recv(csd, full_buffer, sizeof(full_buffer) - 2, 0);
	full_buffer[len] = '\0';
	char *end = full_buffer + len - 1;
	// remove any trailing spaces
	while((end != full_buffer) && (*end <= ' ')) {
		*end-- = '\0';
	}

	// read for which transmitter(s) the command needs to be executed
	// format ctlberry transmitter1,transmitter2,...|all action
	int do_fortransmitter[MAXTRANSMITTERS]; 
	int transmittersspecified = 0;
	bzero(do_fortransmitter, sizeof(do_fortransmitter));
	if (strncmp(full_buffer, "all", 3) == 0) {
		for (int j = 0; j<nr_transmitters;j++) {
			do_fortransmitter[j]=1;
			transmittersspecified++;
		}
	}
	else {
		int f=0; int t=0;
		char transmittername[32];
		bzero(transmittername, sizeof(transmittername));
		do {
			if (full_buffer[f] != ',' && full_buffer[f] != ' ')
				transmittername[t++]=full_buffer[f];
			
			if (t) {
				for (int k=0; k<nr_transmitters;k++) {
					if (strcmp(mmr70[k].name, transmittername) == 0) {
						do_fortransmitter[k]=1;
						transmittersspecified++;
						bzero(transmittername, sizeof(transmittername));
						t=0;
						break;
					}
				}
			}
		f++;
		if (full_buffer[f] == ' ' || full_buffer[f] == 0)
				break;
		} while (1);
	} 

	if (!transmittersspecified) {
		syslog(LOG_NOTICE, "Transmitter(s) missing. Use: cltfmberry transmitter1[,transmitter..]|all <command>\n");
		close(csd);
		return -1;
	}

	int i=0;
	while (full_buffer[i++] != ' ');
	strncpy(arg_buffer, full_buffer+i, sizeof(arg_buffer)-i);

	for (int transmitter=0;transmitter<nr_transmitters;transmitter++) {
		do {
			const char *arg;

			if (do_fortransmitter[transmitter]) {

				if (str_is_arg(arg_buffer, "set freq", &arg))
				{
					int frequency = atoi(arg);
					
					tca9548a_select_port(mmr70[transmitter].i2c_mplexindex, mmr70[transmitter].i2c_mplexport);
					if ((frequency >= 76000) && (frequency <= 108000))
					{
						syslog(LOG_NOTICE, "Changing frequency...\n");
						ns741_set_frequency(transmitter,frequency);
						mmr70[transmitter].frequency = frequency;
					}
					else
					{
						syslog(LOG_NOTICE, "Bad frequency.\n");
					}
					break;
				}

				if (str_is(arg_buffer, "poweroff"))
				{
					tca9548a_select_port(mmr70[transmitter].i2c_mplexindex, mmr70[transmitter].i2c_mplexport);
					ns741_power(transmitter,0);
					mmr70[transmitter].power = 0;
					break;
				}

				if (str_is(arg_buffer, "poweron"))
				{
					tca9548a_select_port(mmr70[transmitter].i2c_mplexindex, mmr70[transmitter].i2c_mplexport);
					ns741_power(transmitter,1);
					ns741_rds(transmitter,1);
					ns741_rds_reset_radiotext(transmitter);
					mmr70[transmitter].power = 1;
					break;
				}

				if (str_is(arg_buffer, "muteon"))
				{
					tca9548a_select_port(mmr70[transmitter].i2c_mplexindex, mmr70[transmitter].i2c_mplexport);
					ns741_mute(transmitter,1);
					mmr70[transmitter].mute = 1;
					break;
				}

				if (str_is(arg_buffer, "muteoff"))
				{
					tca9548a_select_port(mmr70[transmitter].i2c_mplexindex, mmr70[transmitter].i2c_mplexport);
					ns741_mute(transmitter, 0);
					mmr70[transmitter].mute = 0;
					break;
				}

				if (str_is(arg_buffer, "gainlow"))
				{
					tca9548a_select_port(mmr70[transmitter].i2c_mplexindex, mmr70[transmitter].i2c_mplexport);
					ns741_input_gain(transmitter,1);
					mmr70[transmitter].gain = 1;
					break;
				}

				if (str_is(arg_buffer, "gainoff"))
				{
					tca9548a_select_port(mmr70[transmitter].i2c_mplexindex, mmr70[transmitter].i2c_mplexport);
					ns741_input_gain(transmitter,0);
					mmr70[transmitter].gain = 0;
					break;
				}

				if (str_is_arg(arg_buffer, "set volume", &arg))
				{
					int volume = atoi(arg);

					tca9548a_select_port(mmr70[transmitter].i2c_mplexindex, mmr70[transmitter].i2c_mplexport);
					if ((volume >= 0) && (volume <= 6))
					{
						syslog(LOG_NOTICE, "Changing volume level...\n");
						ns741_volume(transmitter,volume);
						mmr70[transmitter].volume = volume;
					}
					else
					{
						syslog(LOG_NOTICE, "Bad volume level. Range 0-6\n");
					}
					break;
				}

				if (str_is_arg(arg_buffer, "set stereo", &arg))
				{
					tca9548a_select_port(mmr70[transmitter].i2c_mplexindex, mmr70[transmitter].i2c_mplexport);
					if (str_is(arg, "on"))
					{
						syslog(LOG_NOTICE, "Enabling stereo signal...\n");
						ns741_stereo(transmitter, 1);
						mmr70[transmitter].stereo = 1;
						break;
					}
					if (str_is(arg, "off"))
					{
						syslog(LOG_NOTICE, "Disabling stereo signal...\n");
						ns741_stereo(transmitter, 0);
						mmr70[transmitter].stereo = 0;
					}
					break;
				}

				if (str_is_arg(arg_buffer, "set txpwr", &arg))
				{
					int txpwr = atoi(arg);

					tca9548a_select_port(mmr70[transmitter].i2c_mplexindex, mmr70[transmitter].i2c_mplexport);
					if ((txpwr >= 0) && (txpwr <= 3))
					{
						syslog(LOG_NOTICE, "Changing transmit power...\n");
						ns741_txpwr(transmitter, txpwr);
						mmr70[transmitter].txpower = txpwr;
					}
					else
					{
						syslog(LOG_NOTICE, "Bad transmit power. Range 0-3\n");
					}
					break;
				}

				if (str_is_arg(arg_buffer, "set rdstext", &arg))
				{
					strncpy (mmr70[transmitter].rdstext, arg, 64);
					ns741_rds_set_radiotext (transmitter, mmr70[transmitter].rdstext);
					break;
				}

				if (str_is_arg(arg_buffer, "set rdsid", &arg))
				{
					bzero (mmr70[transmitter].rdsid, sizeof(mmr70[transmitter].rdsid));
					strncpy (mmr70[transmitter].rdsid, arg, 8);
					ns741_rds_set_progname(transmitter, mmr70[transmitter].rdsid);
					ns741_rds_reset_radiotext(transmitter);
					break;
				}

				if (str_is_arg(arg_buffer, "set rdspi", &arg))
				{
					int rds_pi = strtol(arg, NULL, 16);
					if ((rds_pi >= 0x0000) && (rds_pi <= 0xFFFF))
					{
						ns741_rds_set_rds_pi(transmitter, rds_pi);
						mmr70[transmitter].rdspi = rds_pi;
					}
					break;
				}	

				if (str_is_arg(arg_buffer, "set rdspty", &arg))
				{
					int rds_pty = atoi(arg);
					if ((rds_pty >= 0) && (rds_pty < 32))
					{
						ns741_rds_set_rds_pty(transmitter, rds_pty);
						mmr70[transmitter].rdspty = rds_pty;
					}
					break;
				}					
				
				if (str_is(arg_buffer, "die") || str_is(arg_buffer, "stop"))
				{
					run = 0;
					syslog(LOG_NOTICE, "Shutting down.\n");
					break;
				}

				if (str_is_arg(arg_buffer, "rdsdebug on", &arg))
				{
					ns741_rds_debug(1);
					break;
				}

				if (str_is(arg_buffer, "status"))
				{
					char status_buffer[256];
					bzero(status_buffer, sizeof(status_buffer));
					sprintf(status_buffer, "\033[0;36m\x23%d name: %s\033[0;0m freq: %dKHz txpwr: %.2fmW power: '%s' mute: '%s' gain: '%s' volume: '%d' stereo: '%s' rds: '%s' rdspi: 0x%04X rdspty: %d rdsid: '%s' rdstext: '%s'\n",
						transmitter,
						mmr70[transmitter].name,
						mmr70[transmitter].frequency,
						txpower[mmr70[transmitter].txpower],
						mmr70[transmitter].power ? "on" : "off",
						mmr70[transmitter].mute ? "on" : "off",
						mmr70[transmitter].gain ? "on" : "off",
						mmr70[transmitter].volume,
						mmr70[transmitter].stereo ? "on" : "off",
						mmr70[transmitter].rds ? "on" : "off",
						mmr70[transmitter].rdspi,
						mmr70[transmitter].rdspty,
						mmr70[transmitter].rdsid, 
						mmr70[transmitter].rdstext);

					write(csd, status_buffer, strlen(status_buffer) + 1);
					break;
				}

				//still here? command not recognised. Need to get out of the loop
				break;
			}
			else
				break;
		} while(run);
	}

	close(csd);
	return 0;
}
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

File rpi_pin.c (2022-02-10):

/*
	The MIT License (MIT)

	Copyright (c) 2013 Andrey Chilikin (achilikin@gmail.com)

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
	THE SOFTWARE IS PROVIDED "AS IS", WITHOUT WARRANTY OF ANY KIND, EXPRESS OR
	IMPLIED, INCLUDING BUT NOT LIMITED TO THE WARRANTIES OF MERCHANTABILITY,
	FITNESS FOR A PARTICULAR PURPOSE AND NONINFRINGEMENT. IN NO EVENT SHALL THE
	AUTHORS OR COPYRIGHT HOLDERS BE LIABLE FOR ANY CLAIM, DAMAGES OR OTHER
	LIABILITY, WHETHER IN AN ACTION OF CONTRACT, TORT OR OTHERWISE, ARISING FROM,
	OUT OF OR IN CONNECTION WITH THE SOFTWARE OR THE USE OR OTHER DEALINGS IN
	THE SOFTWARE.
*/

#include <stdio.h>
#include <fcntl.h>
#include <errno.h>
#include <stdlib.h>
#include <syslog.h>

#include "rpi_pin.h"

#if _DEBUG
#define _IFDEB(x) do { x; } while(0)
#else
#define _IFDEB(x)
#endif

static const char *irq_mode[] = { "none\n", "rising\n", "falling\n", "both\n" };

static uint8_t valid_pins_r1[64] =
{
//  pin index
//  0 0 0 0 0 0 0 0 0 0 1 1 1 1 1 1 1 1 1 1 2 2 2 2 2 2 2 2 2 2 3 3
//  0 1 2 3 4 5 6 7 8 9 0 1 2 3 4 5 6 7 8 9 0 1 2 3 4 5 6 7 8 9 0 1
	1,1,0,0,1,0,0,1,1,1,1,1,0,0,1,1,0,1,1,0,0,1,1,1,1,1,0,0,0,0,0,0
};

static uint8_t valid_pins_r2[64] =
{
//  pin index
//  0 0 0 0 0 0 0 0 0 0 1 1 1 1 1 1 1 1 1 1 2 2 2 2 2 2 2 2 2 2 3 3
//  0 1 2 3 4 5 6 7 8 9 0 1 2 3 4 5 6 7 8 9 0 1 2 3 4 5 6 7 8 9 0 1
	0,0,1,1,1,0,0,1,1,1,1,1,0,0,1,1,0,1,1,0,0,0,1,1,1,1,0,1,1,1,1,1
};

static uint8_t *pvalid_pins = valid_pins_r2;

static int pin_fds[64];

#define FPIN_EXPORTED  0x0001
#define FPIN_DIR_INPUT 0x0020

static int pin_flags[64];

int rpi_pin_init(int pi_revision)
{
	if (pi_revision == 1)
		pvalid_pins = valid_pins_r1;

	return 0;
}

int rpi_pin_export(uint8_t pin, enum PIN_DIRECTION dir)
{
	FILE *fd;
	char file[128];

	if ((pin > 63) || !pvalid_pins[pin]) {
		_IFDEB(fprintf(stderr, "%s: invalid pin #%u\n", __func__, pin));
		return -1;
	}

	if ((fd = fopen ("/sys/class/gpio/export", "w")) == NULL) {
		_IFDEB(fprintf(stderr, "%s: unable to export pin #%u\n", __func__, pin));
		return -1;
	}
	fprintf(fd, "%d\n", pin);
	fclose(fd);

	sprintf(file, "/sys/class/gpio/gpio%d/direction", pin);
	if ((fd = fopen (file, "w")) == NULL) {
		_IFDEB(fprintf(stderr, "%s: unable to set direction for pin #%u\n", __func__, pin));
		return -1;
	}

	pin_flags[pin] |= FPIN_EXPORTED;
	if (dir == RPI_INPUT)
		pin_flags[pin] |= FPIN_DIR_INPUT;
	fprintf(fd, (dir == RPI_INPUT) ? "in\n" : "out\n");
	fclose(fd);

	sprintf(file, "/sys/class/gpio/gpio%d/value", pin);
	pin_fds[pin] = open(file, O_RDWR);

	return 0;
}

int rpi_pin_set_dir(uint8_t pin, enum PIN_DIRECTION dir)
{
	FILE *fd;
	char file[128];

	if ((pin > 63) || !pvalid_pins[pin])
		return -1;
	
	if (!(pin_flags[pin] & FPIN_EXPORTED))
		return -1;

	sprintf(file, "/sys/class/gpio/gpio%d/direction", pin);
	if ((fd = fopen (file, "w")) == NULL) {
		_IFDEB(fprintf(stderr, "%s: unable to set direction for pin #%u\n", __func__, pin));
		return -1;
	}

	if (dir == RPI_INPUT) {
		pin_flags[pin] |= FPIN_DIR_INPUT;
		fprintf(fd, "in\n");
	}
	else {
		pin_flags[pin] &= ~FPIN_DIR_INPUT;
		fprintf(fd, "out\n");
	}
	fclose(fd);

	return 0;
}

// read input value:
//	0 - low
//	1 - high
// -1 - error
int rpi_pin_get(uint8_t pin)
{
	// this will check pin validity as well
	int fd = rpi_pin_fd(pin);

	if (fd < 0)
		return -1;

	if (!(pin_flags[pin] & FPIN_DIR_INPUT))
		return -1;

	return rpi_pin_poll_clear(fd);
}

// set output value
int rpi_pin_set(uint8_t pin, uint8_t value)
{
	// this will check pin validity as well
	int fd = rpi_pin_fd(pin);

	if (fd < 0)
		return -1;

	if (pin_flags[pin] & FPIN_DIR_INPUT)
		return -1;
	
	lseek(fd, 0, SEEK_SET);
	return (write(fd, value ? "1" : "0", 1) == 1) ? 0 : -1;
}

int rpi_pin_unexport(uint8_t pin)
{
	FILE *fd;
	char file[128];

	if ((pin > 63) || !pvalid_pins[pin])
		return -1;

	if (!(pin_flags[pin] & FPIN_EXPORTED))
		return 0;

	if ((fd = fopen ("/sys/class/gpio/unexport", "w")) == NULL) {
		_IFDEB(fprintf(stderr, "%s: unable to unexport pin #%u\n", __func__, pin));
		return -1;
	}
	fprintf(fd, "%d\n", pin);
	fclose(fd);

	pin_flags[pin] = 0;
	close(pin_fds[pin]);
	pin_fds[pin] = -1;

	return 0;
}

// functions for pin change of value edge detection support using poll()

// returns pin's file descriptor
int rpi_pin_fd(uint8_t pin)
{
	if ((pin > 63) || !pvalid_pins[pin])
		return -1;

	if (pin_flags[pin] & FPIN_EXPORTED)
		return pin_fds[pin];

	return -1;
}
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

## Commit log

2022-01-22 many fixes rds now working with multiple transmitters
    [fmberryd.c, ns741.c]
2022-01-26 fix rds pty and disabling rds per transmitterworks
    [fmberryd.c, i2c.c, mcp23017.c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]
2022-02-06 schema added
    [multifmberry.kicad_sch]
2022-02-11 fix transmitter select with ctlberry and typos fixes
    [fmberryd.c]
2022-02-12 photo pcb added

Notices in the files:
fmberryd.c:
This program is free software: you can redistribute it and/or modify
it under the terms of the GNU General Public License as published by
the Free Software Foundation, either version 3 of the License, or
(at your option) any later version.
